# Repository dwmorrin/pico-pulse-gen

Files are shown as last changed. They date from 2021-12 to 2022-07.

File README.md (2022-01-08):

# Pico Pulse Generator

Using the Raspberry Pi Pico microcontroller to produce programmable pulses, suitable for
modular synthesizers.

- 8 programmable steps (expandable)
- 3 programmed outputs (expandable)
- clock output
- internal tempo control via analog pot
- read/write mode to transfer patterns between outputs
  - write mode transfers from the 8 programming buttons to the selected output
  - read mode transfers from the selected output to the 8 programming buttons

Adds rhythmic variation to any module that takes a gate/trigger/clock input.

The multiple, synchronized outputs make simple drum programming easy.

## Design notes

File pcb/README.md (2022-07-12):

thanks to [ncarandini/KiCad-PR-Pico](https://github.com/ncarandini/KiCad-RP-Pico/) for the KiCad pico files.

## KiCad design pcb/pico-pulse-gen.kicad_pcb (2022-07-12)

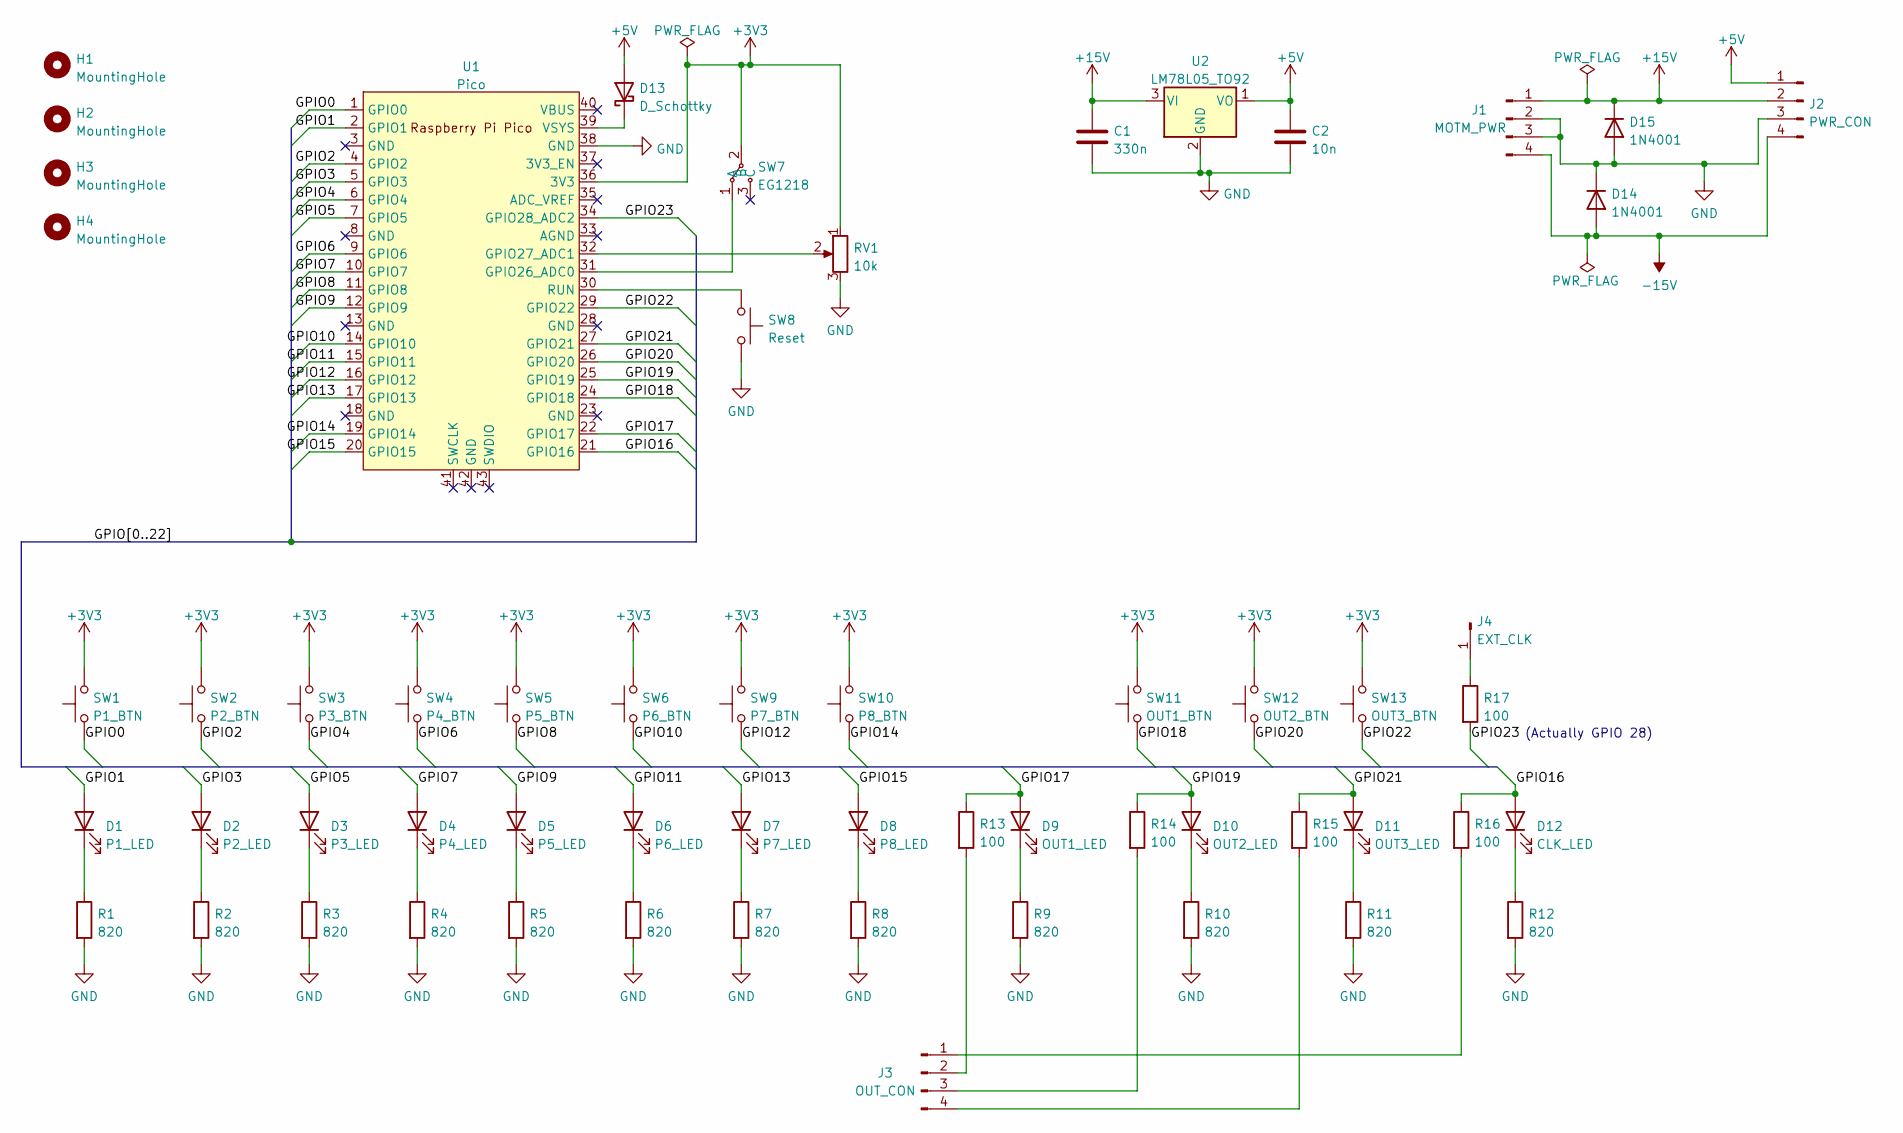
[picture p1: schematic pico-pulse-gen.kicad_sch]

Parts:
C1: 330n; C_Disc_D3.8mm_W2.6mm_P2.50mm
C2: 10n; C_Disc_D3.8mm_W2.6mm_P2.50mm
D1: P1_LED; LED_D3.0mm
D2: P2_LED; LED_D3.0mm
D3: P3_LED; LED_D3.0mm
D4: P4_LED; LED_D3.0mm
D5: P5_LED; LED_D3.0mm
D6: P6_LED; LED_D3.0mm
D7: P7_LED; LED_D3.0mm
D8: P8_LED; LED_D3.0mm
D9: OUT1_LED; LED_D3.0mm
D10: OUT2_LED; LED_D3.0mm
D11: OUT3_LED; LED_D3.0mm
D12: CLK_LED; LED_D3.0mm
D13: D_Schottky; D_DO-34_SOD68_P7.62mm_Horizontal
D14, D15: 1N4001; D_DO-34_SOD68_P7.62mm_Horizontal
H1, H2, H3, H4: MountingHole; MountingHole_2.7mm_M2.5
J1: MOTM_PWR; connector_motm
J2: PWR_CON; PinHeader_1x04_P2.54mm_Vertical
J3: OUT_CON; PinHeader_1x04_P2.54mm_Vertical
J4: EXT_CLK; PinHeader_1x01_P2.54mm_Vertical
R1, R2, R3, R4, R5, R6, R7, R8, R9, R10, R11, R12: 820; R_Axial_DIN0207_L6.3mm_D2.5mm_P7.62mm_Horizontal
R13, R14, R15, R16, R17: 100; R_Axial_DIN0207_L6.3mm_D2.5mm_P7.62mm_Horizontal
RV1: 10k; Potentiometer_Bourns_PTV09A-1_Single_Vertical
SW1: P1_BTN; SW_PUSH_6mm
SW2: P2_BTN; SW_PUSH_6mm
SW3: P3_BTN; SW_PUSH_6mm
SW4: P4_BTN; SW_PUSH_6mm
SW5: P5_BTN; SW_PUSH_6mm
SW6: P6_BTN; SW_PUSH_6mm
SW7: EG1218; slide_switch_e61218
SW8: Reset; SW_PUSH_6mm
SW9: P7_BTN; SW_PUSH_6mm
SW10: P8_BTN; SW_PUSH_6mm
SW11: OUT1_BTN; SW_PUSH_6mm
SW12: OUT2_BTN; SW_PUSH_6mm
SW13: OUT3_BTN; SW_PUSH_6mm
U1: Pico; RPi_Pico_SMD_TH
U2: LM78L05_TO92; TO-92_Inline

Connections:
+3V3: RV1.1, SW1.2, SW2.2, SW3.2, SW4.2, SW5.2, SW6.2, SW7.2 (B), SW9.2, SW10.2, SW11.2, SW12.2, SW13.2, U1.36 (3V3)
+5V: C2.1, D13.2 (A), J2.1, U2.1 (VO)
+15V: C1.1, D15.1 (K), J1.1, J2.2, U2.3 (VI)
-15V: D14.2 (A), J1.4, J2.4
/GPIO0: SW1.1, U1.1 (GPIO0)
/GPIO1: D1.2 (A), U1.2 (GPIO1)
/GPIO2: SW2.1, U1.4 (GPIO2)
/GPIO3: D2.2 (A), U1.5 (GPIO3)
/GPIO4: SW3.1, U1.6 (GPIO4)
/GPIO5: D3.2 (A), U1.7 (GPIO5)
/GPIO6: SW4.1, U1.9 (GPIO6)
/GPIO7: D4.2 (A), U1.10 (GPIO7)
/GPIO8: SW5.1, U1.11 (GPIO8)
/GPIO9: D5.2 (A), U1.12 (GPIO9)
/GPIO10: SW6.1, U1.14 (GPIO10)
/GPIO11: D6.2 (A), U1.15 (GPIO11)
/GPIO12: SW9.1, U1.16 (GPIO12)
/GPIO13: D7.2 (A), U1.17 (GPIO13)
/GPIO14: SW10.1, U1.19 (GPIO14)
/GPIO15: D8.2 (A), U1.20 (GPIO15)
/GPIO16: D12.2 (A), R16.1, U1.21 (GPIO16)
/GPIO17: D9.2 (A), R13.1, U1.22 (GPIO17)
/GPIO18: SW11.1, U1.24 (GPIO18)
/GPIO19: D10.2 (A), R14.1, U1.25 (GPIO19)
/GPIO20: SW12.1, U1.26 (GPIO20)
/GPIO21: D11.2 (A), R15.1, U1.27 (GPIO21)
/GPIO22: SW13.1, U1.29 (GPIO22)
/GPIO23: R17.2, U1.34 (GPIO28_ADC2)
GND: C1.2, C2.2, D14.1 (K), D15.2 (A), J1.2, J1.3, J2.3, R1.2, R2.2, R3.2, R4.2, R5.2, R6.2, R7.2, R8.2, R9.2, R10.2, R11.2, R12.2, RV1.3, SW8.2, U1.38 (GND), U2.2 (GND)
unnamed: D1.1 (K), R1.1
unnamed: D2.1 (K), R2.1
unnamed: D3.1 (K), R3.1
unnamed: D4.1 (K), R4.1
unnamed: D5.1 (K), R5.1
unnamed: D6.1 (K), R6.1
unnamed: D7.1 (K), R7.1
unnamed: D8.1 (K), R8.1
unnamed: D9.1 (K), R9.1
unnamed: D10.1 (K), R10.1
unnamed: D11.1 (K), R11.1
unnamed: D12.1 (K), R12.1
unnamed: D13.1 (K), U1.39 (VSYS)
unnamed: J3.1, R16.2
unnamed: J3.2, R13.2
unnamed: J3.3, R14.2
unnamed: J3.4, R15.2
unnamed: J4.1, R17.1
unnamed: RV1.2, U1.32 (GPIO27_ADC1)
unnamed: SW7.1 (A), U1.31 (GPIO26_ADC0)
unnamed: SW8.1, U1.30 (RUN)

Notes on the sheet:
(Actually GPIO 28)

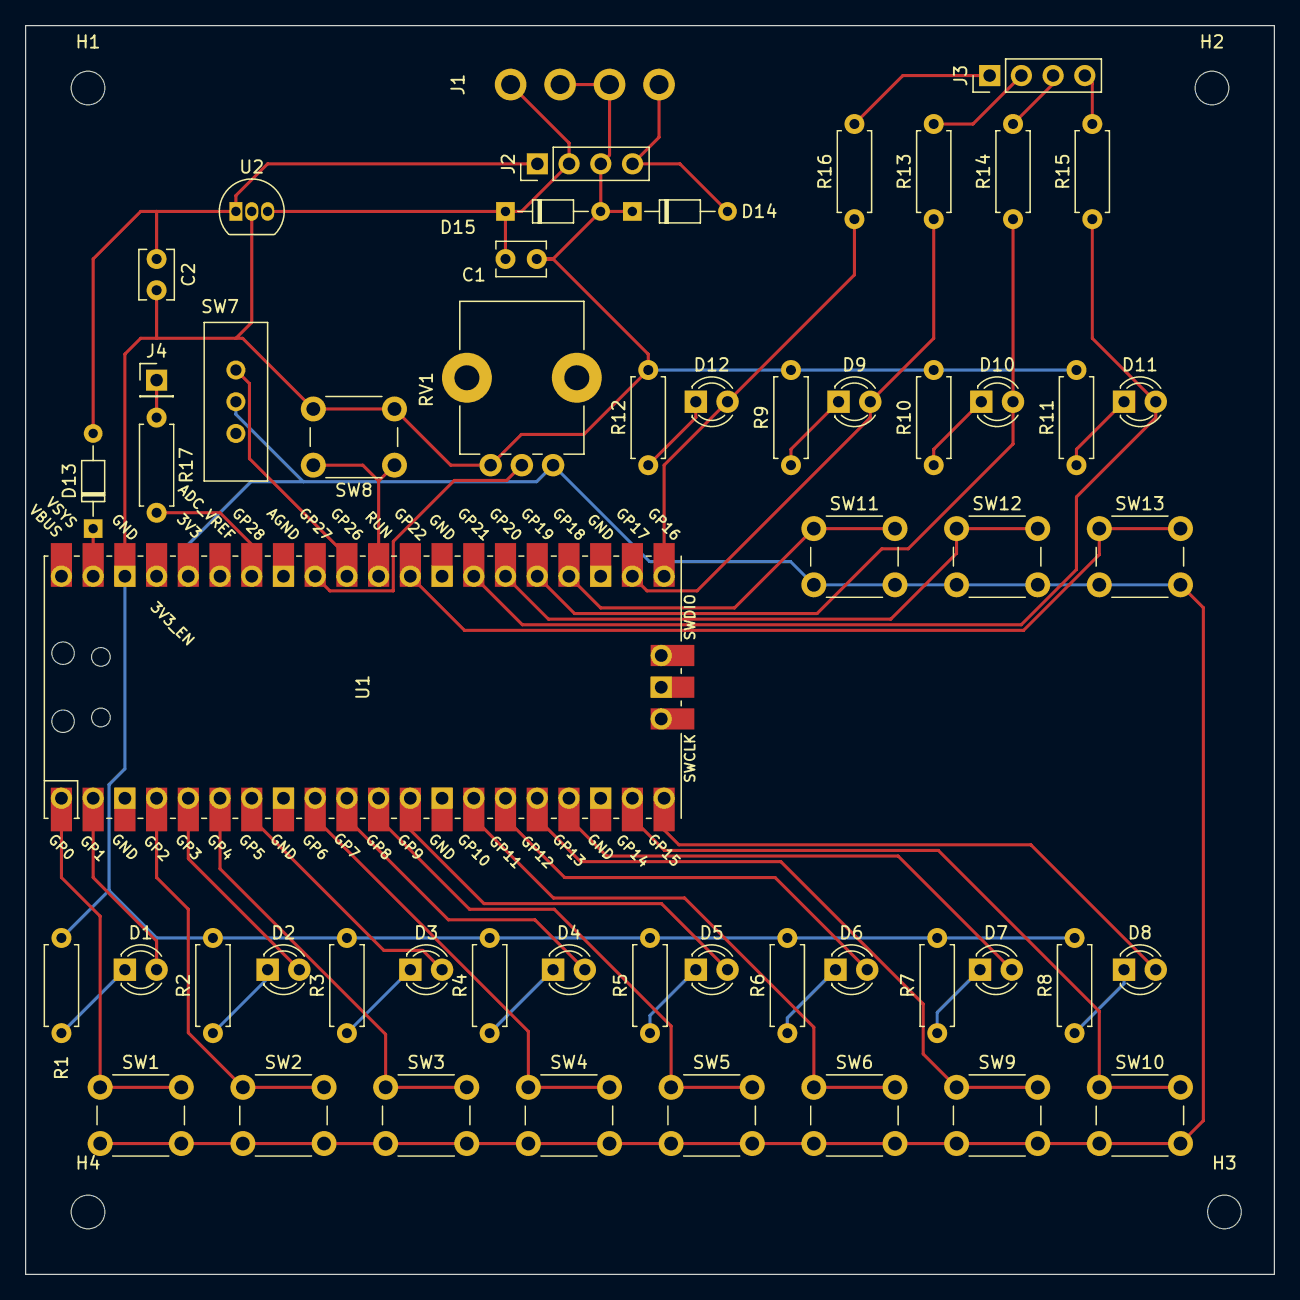
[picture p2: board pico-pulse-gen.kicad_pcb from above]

Board: 2 copper layers, 100.0 x 100.0 mm, 58 parts (0 on the bottom side), 50 nets.

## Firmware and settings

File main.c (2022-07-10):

#include <stdio.h>
#include "hardware/adc.h"
#include "hardware/gpio.h"
#include "pico/stdlib.h"
#include "pico/time.h"
#include "Button.h"

#define ARRAY_LENGTH(array) (sizeof(array) / sizeof(array[0]))

uint tempo_delay_ms = 0;

// map of the GPIO pins
enum PIN_ASSIGN
{
    PROG_BTN_1,
    PROG_LED_1,
    PROG_BTN_2,
    PROG_LED_2,
    PROG_BTN_3,
    PROG_LED_3,
    PROG_BTN_4,
    PROG_LED_4,
    PROG_BTN_5,
    PROG_LED_5,
    PROG_BTN_6,
    PROG_LED_6,
    PROG_BTN_7,
    PROG_LED_7,
    PROG_BTN_8,
    PROG_LED_8,
    CLK_LED,
    PATT_OUT_1,
    PATT_BTN_1,
    PATT_OUT_2,
    PATT_BTN_2,
    PATT_OUT_3,
    PATT_BTN_3,
    NOT_USED,
    NOT_USED_,
    BUILT_IN_LED,
    READ_WRITE,
    TEMPO_POT,
};

#define PATTERN_LENGTH 8

struct Pattern
{
    uint8_t pin_out;            // output pin
    struct Button load;         // load button
    bool state[PATTERN_LENGTH]; // state of the pattern
};

struct Pattern_Container
{
    uint8_t index;
    struct Pattern clock;
    struct Pattern progammable[3];
};

uint8_t pattern_index = 0;

struct Pattern patterns[] = {
    {
        .pin_out = PATT_OUT_1,
        .load = {
            .pin = PATT_BTN_1,
            .no_led = true,
        },
        .state = {0, 0, 0, 0, 0, 0, 0, 0},
    },
    {
        .pin_out = PATT_OUT_2,
        .load = {
            .pin = PATT_BTN_2,
            .no_led = true,
        },
        .state = {0, 0, 0, 0, 0, 0, 0, 0},
    },
    {
        .pin_out = PATT_OUT_3,
        .load = {
            .pin = PATT_BTN_3,
            .no_led = true,
        },
        .state = {0, 0, 0, 0, 0, 0, 0, 0},
    }};

// no load button for clock; always on
const struct Pattern clock = {
    .pin_out = CLK_LED,
    .state = {1, 1, 1, 1, 1, 1, 1, 1}};

int64_t onBeat(alarm_id_t, void *);
int64_t onHalfBeat(alarm_id_t id, void *data)
{
    gpio_clr_mask(
        (1 << patterns[0].pin_out) |
        (1 << patterns[1].pin_out) |
        (1 << patterns[2].pin_out) |
        (1 << clock.pin_out));
    add_alarm_in_ms(tempo_delay_ms, onBeat, 0, true);
    return 0;
}

int64_t onBeat(alarm_id_t id, void *data)
{
    uint32_t mask = (1 << clock.pin_out);
    for (int i = 0; i < 3; ++i)
        if (patterns[i].state[pattern_index])
            mask |= (1 << patterns[i].pin_out);
    gpio_set_mask(mask);
    pattern_index = (pattern_index + 1) % PATTERN_LENGTH;
    add_alarm_in_ms(tempo_delay_ms, onHalfBeat, 0, true);
    return 0;
}

void Pattern_Update(struct Button *, const unsigned int);
void Pattern_Setup()
{
    // clock is just an LED out
    gpio_init(clock.pin_out);
    gpio_set_dir(clock.pin_out, GPIO_OUT);

    // patterns have a button input and an output
    for (int i = 0; i < 3; ++i)
    {
        gpio_init(patterns[i].pin_out);
        ButtonInit(&patterns[i].load);
        gpio_set_dir(patterns[i].pin_out, GPIO_OUT);
    }

    // READ/WRITE could be slide switch or button that is held when writing
    gpio_init(READ_WRITE);
    gpio_set_dir(READ_WRITE, GPIO_IN);
}

#define MIN_DELAY_MS 50.0
#define MAX_DELAY_MS 1000.0

uint tempo_map(uint16_t adc_value)
{
    return (MIN_DELAY_MS-MAX_DELAY_MS)/4095.0 * adc_value + MAX_DELAY_MS;
}

int main()
{
    stdio_init_all();

    struct Button program_btns[] = {
        {.pin = 0, .led_pin = 1},
        {.pin = 2, .led_pin = 3},
        {.pin = 4, .led_pin = 5},
        {.pin = 6, .led_pin = 7},
        {.pin = 8, .led_pin = 9},
        {.pin = 10, .led_pin = 11},
        {.pin = 12, .led_pin = 13},
        {.pin = 14, .led_pin = 15},
    };
    for_each_button(program_btns, ARRAY_LENGTH(program_btns), ButtonInit);

    Pattern_Setup();

    adc_init();
    adc_gpio_init(TEMPO_POT);
    adc_select_input(1);
    tempo_delay_ms = tempo_map(adc_read());

    alarm_id_t alarm_id = add_alarm_in_ms(0, onBeat, 0, true);

    while (1)
    {
        for_each_button(program_btns, ARRAY_LENGTH(program_btns), ButtonUpdate);
        Pattern_Update(program_btns, ARRAY_LENGTH(program_btns));
        tempo_delay_ms = tempo_map(adc_read());
    }
}

void Pattern_Update(struct Button *program_btns, const uint length)
{
    for (int i = 0; i < 3; ++i)
    {
        ButtonUpdate(&patterns[i].load);
        if (patterns[i].load.pressed_flag)
        {
            patterns[i].load.pressed_flag = false;
            // high is a write
            if (gpio_get(READ_WRITE))
                for (int index = 0; index < length; ++index)
                    patterns[i].state[index] = program_btns[index].active;
            // low is a read
            else
                for (int index = 0; index < length; ++index)
                {
                    // load pattern into the buttons and button LEDs
                    program_btns[index].active = patterns[i].state[index];
                    gpio_put(program_btns[index].led_pin, patterns[i].state[index]);
                }
        }
    }

}

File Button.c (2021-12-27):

#include <stdio.h>
#include "pico/stdlib.h"
#include "hardware/gpio.h"
#include "Button.h"

#define NOW() (to_us_since_boot(get_absolute_time()))

void ButtonInit(struct Button *b)
{
    gpio_init(b->pin);
    gpio_set_dir(b->pin, GPIO_IN);
    if (!b->no_led)
    {
        gpio_init(b->led_pin);
        gpio_set_dir(b->led_pin, GPIO_OUT);
    }
}

void ButtonUpdate(struct Button *b)
{
    bool pin_is_high = gpio_get(b->pin);
    if (!b->pressed && b->release_delaying)
    {
        if (b->delay_count < BUTTON_ONE_SHOT_DELAY_MAX)
            ++b->delay_count;
        if (b->delay_count == BUTTON_ONE_SHOT_DELAY_MAX)
            b->release_delaying = false;
    }
    else if (!b->pressed && pin_is_high)
    {
        b->pressed = true;
        b->active = !b->active;
        b->release_delaying = true;
        b->delay_count = 0;
        if (!b->no_led)
            gpio_put(b->led_pin, b->active);
        b->last_press_time = NOW();
        b->pressed_flag = true;
        printf("Button %d pressed\n", b->pin);
    }
    else if (b->pressed)
    {
        if (b->release_delaying && b->delay_count < BUTTON_ONE_SHOT_DELAY_MAX)
            ++b->delay_count;
        if (b->delay_count == BUTTON_ONE_SHOT_DELAY_MAX)
        {
            if (b->release_delaying)
            {
                b->release_delaying = false;
                printf("Button %d delay done [%d]\n", b->pin, NOW() - b->last_press_time);
            }
            if (!pin_is_high)
            {
                b->pressed = false;
                b->pressed_flag = false;
                b->delay_count = 0;
                b->release_delaying = true;
                printf("Button %d released\n", b->pin);
            }
        }
    }
}

void for_each_button(struct Button *buttons, const uint length, void (*cb)(struct Button *))
{
    for (uint i = 0; i < length; ++i)
        cb(&buttons[i]);
}

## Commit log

2021-12-27 feat: toggle buttons and blink
2022-01-08 feat: 3 programmable patterns
    adds read/write button to recall stored patterns
    fix: ignores .DS_Store
    [main.c]
2022-01-08 feat: adds adc for tempo ctrl
2022-07-10 feat: adds pcb design
    [pico-pulse-gen.kicad_pcb, pico-pulse-gen.kicad_sch]
2022-07-12 wip: pcb layout
    [pico-pulse-gen.kicad_pcb, pico-pulse-gen.kicad_sch]
2022-07-12 feat: routed pcb
    [pico-pulse-gen.kicad_pcb, pico-pulse-gen.kicad_sch]
